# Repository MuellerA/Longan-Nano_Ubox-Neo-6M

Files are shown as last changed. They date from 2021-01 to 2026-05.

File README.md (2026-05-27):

# GPS Receiver and Logger

Using ```Longan Nano``` with an ```u-blox``` GPS module to display and record UTC time and GPS position data. The GPS receiver must implement the ubx protocol, tested with u-blox 6, 7, 10.

## Usage

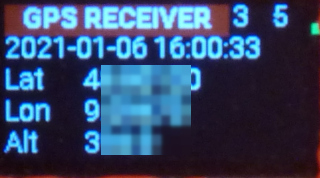
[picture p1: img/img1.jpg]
GPS Position
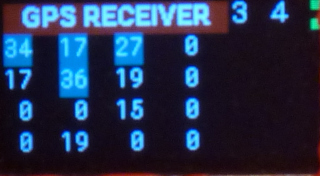
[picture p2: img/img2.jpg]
Satellite Info
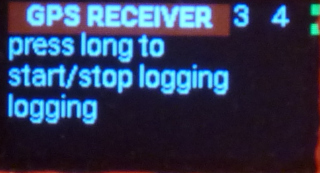
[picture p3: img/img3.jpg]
Logging
   

The GPS Receiver has three screens: *GPS Position*, *Satellite Info* and *Logging*. Use a short button press to toggle between *GPS Position* screen and *Satellite Info* screen. A long button press will select the *Logging* screen. Another long button press will start / stop logging to the SD card.

The top line of all screens show
- GPS fix (0: none; 2: 2D fix; 3: 3D fix)
- number of used satellites
- GPS module connection indicator (green blinking: connected, red: connection lost)
- Logging status indicator (red: logging off, green: logging data, yellow: waiting for data)

## Logging

The logging will start when the UTC time and GPS position are found and will then be update every five seconds. The file name will be the start UTC time with the extension csv.
Always stop logging before power off, else data will be lost and the file system might get corrupted.

The logfile format is compatible with [GPSBabel](http://www.gpsbabel.org/index.html)'s [unicsv](http://www.gpsbabel.org/htmldoc-1.7.0/fmt_unicsv.html) format. GPSBabel can convert the logfile to many different formats (try ```gpsbabel -h``` for a full list of formats). E.g. to create a kml file for Google Earth use the command:

```
gpsbabel -i unicsv -f 'yyymmdd-hhmmss.csv' -o kml -F 'yyymmdd-hhmmss.kml'
```

The [example.csv](img/example.csv) converted to Google Earth:  
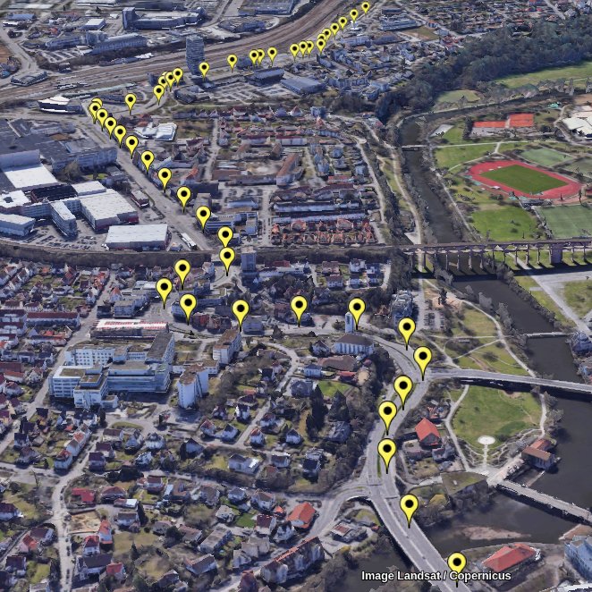
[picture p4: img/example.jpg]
example
[](img/example.jpg)

## Compilation

A ```Longan Nano``` is required, the ```Longan Nano Lite``` has not enough memory.
Use the PlatformIO environment option to select which USART the GPS module is connected to: ```-e usart0``` or ```-e usart1```.

```
pio run -e usart0 -t upload
```

## 3D Print STL Files

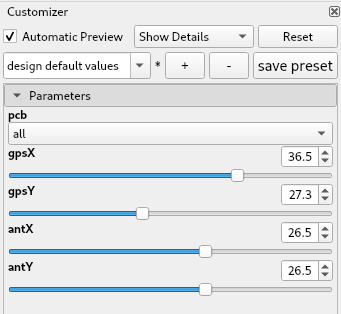
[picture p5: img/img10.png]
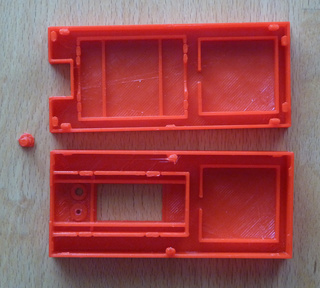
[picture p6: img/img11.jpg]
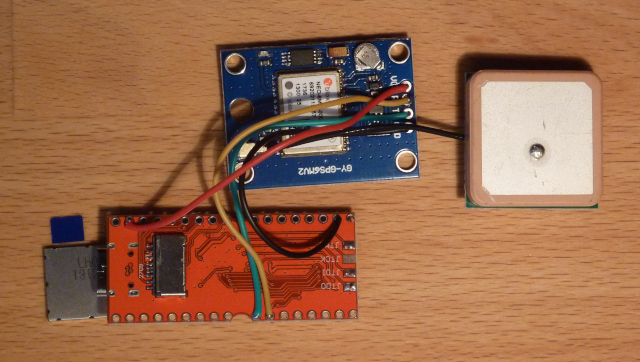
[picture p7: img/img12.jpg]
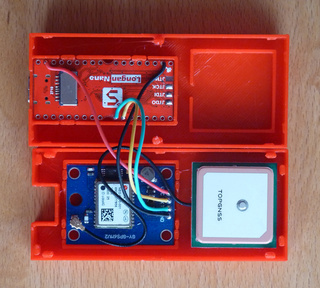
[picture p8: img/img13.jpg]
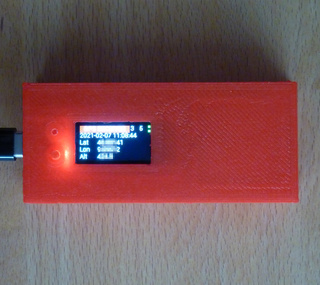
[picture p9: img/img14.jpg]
[](img/img10.png) [](img/img11.jpg) [](img/img12.jpg) [](img/img13.jpg) [](img/img14.jpg)

The [OpenSCAD](http://www.openscad.org/downloads.html) file ```hw/gps.scad``` can be used to create STL files for a 3D printed housing. The dimensions of the GPS board and antenna can be changed using the Customizer: In menu *View* uncheck *Hide Customizer*, in the Customizer dialog modify the parameters, press *F6* and then *F7* to create the STL files. When printing the button might need a brim.

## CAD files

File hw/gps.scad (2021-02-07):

////////////////////////////////////////////////////////////////////////////////
// gps.scad
////////////////////////////////////////////////////////////////////////////////

// https://github.com/MuellerA/Thingiverse.git#ac669d2e31545f4aca594795901329ed9a7b87eb
use <../../../3D Druck/Thingiverse/PCB/pcb.scad> ;

pcb = "all" ; // [top,bottom,button,all,testGps,testAnt]

// see measure.svg

gpsX = 36.5 ; // [15:0.1:45]
gpsY = 27.3 ; // [15:0.1:45]

antX = 26.5 ; // [5:0.1:40]
antY = 26.5 ; // [5:0.1:40]

/* [Hidden] */

nanoX  = 46.5 ;
nanoY  = 20.5 ;

minOX = 3 ;
minOY = 3 ;
dX    = 4 ;

minGpsOX = 9 ;

wallWidth = 0.8 ;
$fn = 40 ;

// calc total size excl outer wall

totTopX = 3*wallWidth + nanoX            + dX + antX + minOX ;
totBotX = 4*wallWidth + minGpsOX + gpsX  + dX + antX + minOX ;

totX = max(totTopX, totBotX) ;

totNanY = 2*wallWidth + 2*minOY + nanoY ;
totAntY = 2*wallWidth + 2*minOY + antY ;
totGpsY = 2*wallWidth + 2*minOY + gpsY ;

totY = max(totNanY, totAntY, totGpsY) ;

// calc offsets

offsetAntX = -antX/2 + totX - minOX - wallWidth ;
offsetGpsX = -gpsX/2 + totX - minOX - antX - dX - 3*wallWidth ;

////////////////////////////////////////////////////////////////////////////////

module base(height)
{
  translate([totX/2, 0, height/2])
    difference()
  {
    translate([0, 0, -wallWidth/2])
      cube([totX+2*wallWidth, totY+2*wallWidth, height+wallWidth], center=true) ;
    translate([0, 0, +wallWidth/2])
      cube([totX            , totY            , height+wallWidth], center=true) ;
  }
}

////////////////////////////////////////////////////////////////////////////////

module antenna()
{
  antZ = 4 ;

  difference()
  {
    translate([0, 0, antZ/2])
      cube([antX+2*wallWidth, antY+2*wallWidth, antZ], center=true) ;

    translate([0, 0, antZ/2])
      cube([antX            , antY          , 2*antZ], center=true) ;
    translate([-antX/2, 0, antZ/2])
      cube([8, 4, 2*antZ], center=true) ;
  }
}

////////////////////////////////////////////////////////////////////////////////

module gps()
{
  pcbHeight  =  1.2 ;
  wallWidth  =  0.8 ;
  railHeight =  2.0 ;
  railOffset =  8.0 ;

  clip = [ 3, 3.5 ] ;
  PcbHolder(gpsY, gpsX, pcbHeight, wallWidth, railHeight, railOffset,
            clip=clip, fingerHoleEnable=true) ;
}

////////////////////////////////////////////////////////////////////////////////

module hooks(height, top)
{
  w = wallWidth ;
  d = w/2 ;
  points =
    [
      [ [0, 0], [w, -w], [0, -2*w], [-w, -2*w], [-w, 0] ],
      [ [0, 0], [0, -2*w], [w+d, -2*w], [w+d, 0.5*w], [d, 1.5*w], [w+d, 2.5*w], [2*w+d, 2.2*w], [2*w+d, -3*w], [0, -6*w], [-w, -6*w], [-w, 0] ]
    ] ;

  module hook(points)
  {
    rotate([0, 0, 90])
      rotate([90, 0, 0])
      linear_extrude(height=3, center=true)
      polygon(points) ;
  }

  p1 = (top) ? points[0] : points[1] ;
  p2 = (top) ? points[1] : points[0] ;
  
  translate([+totX/2-5, -totY/2, height]) rotate([0, 0,   0]) hook(p1) ;
  translate([0        , -totY/2, height]) rotate([0, 0,   0]) hook(p2) ;
  translate([-totX/2+5, -totY/2, height]) rotate([0, 0,   0]) hook(p1) ;
  translate([+totX/2-5, +totY/2, height]) rotate([0, 0, 180]) hook(p1) ;
  translate([0        , +totY/2, height]) rotate([0, 0, 180]) hook(p2) ;
  translate([-totX/2+5, +totY/2, height]) rotate([0, 0, 180]) hook(p1) ;

  translate([+totX/2  , -totY/2+6  , height]) rotate([0, 0,  90]) hook(p1) ;
  translate([+totX/2  , +totY/2-6  , height]) rotate([0, 0,  90]) hook(p1) ;

  translate([-totX/2  , -totY/2+2.8, height]) rotate([0, 0, 270]) hook(p1) ;
  translate([-totX/2  , +totY/2-2.8, height]) rotate([0, 0, 270]) hook(p1) ;
}

////////////////////////////////////////////////////////////////////////////////

module top()
{
  pcbHeight  =  1.9 ;
  railHeight =  6.0 ;
  railOffset =  2.3 ;

  height = railHeight + pcbHeight + wallWidth + 1 ;
  
  dispLength = 23.9 ;
  dispWidth  = 13.5 ;
  dispOffset =  3.5 ;

  buttonD       = 3.0 ;
  buttonLoffset = nanoX / 2 - 8.9 ;
  buttonWoffset = 3.5 ;

  usbWidth  = 9.9 ;
  usbHeight = 3.9 ;
  usbOffset = 2.0 ;
  
  difference()
  {
    union()
    {
      // base
      base(height) ;

      // nano
      translate([nanoX/2, 0, 0])
      {
        // pcb frame
        rotate([0, 0, 90])
          PcbHolder(nanoX, nanoY, pcbHeight, wallWidth, railHeight, railOffset, clip = [10, 5]) ;

        translate([-dispLength/2+dispOffset-1.5*wallWidth, 0, 2/2]) cube([wallWidth, 20 , 2], center=true) ;

        // button
        bd = buttonD + 2 * 0.4 ;
        translate([-buttonLoffset, buttonWoffset, 0.51]) cylinder(d=bd+2*wallWidth, h=1, center=true) ;
        
        // reset
        translate([-buttonLoffset, -buttonWoffset, 0.51]) cylinder(d=bd+2*wallWidth, h=1, center=true) ;
      }

      // antenna
      translate([offsetAntX, 0, 0]) antenna() ;
    }

    union()
    {
      translate([nanoX/2, 0, 0])
      {
        // display
        translate([dispOffset, 0, 0]) cube([dispLength, dispWidth, 10], center=true) ;

        // button
        bd = buttonD + 2 * 0.4 ;
        translate([-buttonLoffset, buttonWoffset, 0]) cylinder(d=bd, h=10, center=true) ;

        // reset
        translate([-buttonLoffset, -buttonWoffset, 0]) cylinder(d=2, h=10, center=true) ;

        // usb
        translate([-nanoX/2, 0, usbHeight/2+usbOffset])
          cube([5, usbWidth, usbHeight], center=true) ;

        // sdcard
        translate([-nanoX/2, 0, railHeight + pcbHeight + 2])
          cube([5, 12, 4], center=true) ;
      }
    }
  }

  translate([totX/2, 0, 0])
    hooks(height, true) ;
}

////////////////////////////////////////////////////////////////////////////////

module bottom()
{
  sdcardX =  7 ;
  sdcardY = 12 ;
  
  height = 7 ;

  difference()
  {
    union()
    {
      // base
      base(height) ;

      // sdcard
      translate([(sdcardX)/2, 0, height/2])
        cube([sdcardX+2*wallWidth, sdcardY+2*wallWidth, height], center=true) ;

      // gps
      {
        translate([offsetGpsX, 0, 0])
          gps() ;
      }
      
      // antenna
      translate([offsetAntX, 0, 0]) antenna() ;
    }

    union()
    {
      // sdcard
      translate([(sdcardX)/2-wallWidth, 0, height/2])
        cube([sdcardX+2*wallWidth, sdcardY, height*2], center=true) ;
      translate([sdcardX+wallWidth/2, 0, height])
        cube([2*wallWidth, sdcardY, 2], center=true) ;
    }
  }   
  
  translate([totX/2, 0, 0])
    hooks(height, false) ;
}

////////////////////////////////////////////////////////////////////////////////

module button()
{
  cylinder(h=1, d=4.4) ;
  cylinder(h=6, d=2.5) ;
}

////////////////////////////////////////////////////////////////////////////////

if (pcb == "top")
  top() ;
else if (pcb == "bottom")
  bottom() ;
else if (pcb == "button")
  button() ;
else if (pcb == "all")
{
  translate([0, -totY/2 - 5, 0]) bottom() ;
  translate([0, +totY/2 + 5, 0]) top() ;
  translate([-10, 0, -wallWidth]) button() ;
}
else if (pcb == "testGps")
{
  translate([0, 0, -wallWidth/2])
    cube([gpsX+2*wallWidth, gpsY+2*wallWidth, wallWidth], center=true) ;
  gps() ;
}
else if (pcb == "testAnt")
{
  translate([0, 0, -wallWidth/2])
    cube([antX+2*wallWidth, antY+2*wallWidth, wallWidth], center=true) ;
  antenna() ;
}

////////////////////////////////////////////////////////////////////////////////
// EOF
////////////////////////////////////////////////////////////////////////////////

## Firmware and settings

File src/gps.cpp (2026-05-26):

//////////////////////////////////////////////////////////////////////////////
// gps.cpp
////////////////////////////////////////////////////////////////////////////////

#include "disp.h"
#include "ubx.h"
#include "file.h"
#include "Longan/fatfs.h"
#include "Longan/lcd.h"
#include "GD32VF103/gpio.h"

using ::RV::GD32VF103::Gpio ;
using ::RV::Longan::FatFs ;
using ::RV::Longan::Lcd ;

Gpio &button(Gpio::gpioA8()) ;
FatFs &fatfs{FatFs::fatfs()} ;
extern Lcd &lcd ;

volatile bool ubxAscFound{false} ;

////////////////////////////////////////////////////////////////////////////////

int _put_char(int ch) // used by printf
{
  lcd.put((char)ch) ;
  return ch ;
}

////////////////////////////////////////////////////////////////////////////////

uint8_t buttonPressed()
{
  struct State
  {
    State() : _value{0x00}, _tick{TickTimer::now()} {}
    uint8_t  _value ;
    uint64_t _tick ;
  } ;
  static State last ;
  static State current ;

  uint64_t now = TickTimer::now() ;
  if ((now - current._tick) < TickTimer::usToTick(2500))
    return 0 ;

  current._tick = now ;
  current._value = (current._value << 1) | button.get() ;
  if ((current._value == last._value) ||
      ((current._value != 0x00) && (current._value != 0xff)))
    return 0 ;

  uint32_t ms = TickTimer::tickToMs(current._tick - last._tick) ;
  last = current ;
  if (current._value)
    return 0 ;
  return (ms < 600) ? 1 : 2 ;
}

void getTimeUtc(const UbxNav &nav, FatFs::Time &time)
{
  if (!nav.timeUtcValid())
    return ;

  const UbxNavTimeUtc &timeUtc = nav.timeUtc() ;
  if (timeUtc.valid & 0b100)
  {
    time.year   = timeUtc.year - 2000 ;
    time.month  = timeUtc.month ;
    time.day    = timeUtc.day ;
    time.hour   = timeUtc.hour ;
    time.minute = timeUtc.min ;
    time.second = timeUtc.sec ;
  }
}

////////////////////////////////////////////////////////////////////////////////

int main()
{
  button.setup(Gpio::Mode::IN_FL) ;

  dispSetup() ;
  {
    lcd.color(0xffffffUL, 0xa00000UL) ;
    lcd.clear() ;
    lcd.put("https://git.io/JLHU1", 80, 48) ;
    lcd.font(&::RV::Longan::Roboto_Bold7pt7b) ;
    lcd.put("GPS RECEIVER 2.0", 80, 24) ;
    
    LcdArea laUbx(Lcd::lcd(), 0, 160, 64, 16) ;
    laUbx.clear() ;
    ubxSetup(laUbx) ;

    TickTimer t(1250) ;
    bool bp = false ;
    while (!t())
      bp |= buttonPressed() ;
    if (bp)
      while (!buttonPressed()) ;
    
    lcd.clear(0x000000UL) ;
    lcd.put("   GPS RECEIVER   ") ;
  }
  
  LcdArea laData(Lcd::lcd(), 0, 150, 16, 64) ;
  
  UbxRx ubxRx ;

  DispGpsFix    dispGpsFix ;
  DispSats      dispSats   ;
  DispTow       dispTow    ;
  DispSvInfo    dispSvInfo ;
  DispTime      dispTime   ;
  DispPos       dispPos    ;
  DispFile      dispFile   ;
  DispAscFound  dispAscFound(1100) ;
  DispFileState dispFileState ;
  
  UbxNav ubxNav ;

  fatfs.setup([&ubxNav](FatFs::Time &time){ getTimeUtc(ubxNav, time) ; }) ;
  File logging(fatfs, ubxNav) ;

  enum class Page { main, sat, file } ;
  Page page{Page::main} ;
  
  bool force{true} ;
  uint8_t sched{0} ;

  dispPos.label() ;
  
  while (true)
  {
    while (ubxRx.poll())
    {
      if (ubxRx.valid())
      {
        if (ubxRx.clsId() == 0x01) // Nav
        {
          switch (ubxRx.msgId())
          {
          case 0x02: ubxNav.posllh (ubxRx.data()) ; break ;
          case 0x03: ubxNav.status (ubxRx.data()) ; break ;
          case 0x21: ubxNav.timeUtc(ubxRx.data()) ; break ;
          case 0x30: ubxNav.svinfo (ubxRx.data()) ; break ;
          case 0x35: ubxNav.sat    (ubxRx.data()) ; break ;
          }
        }
      }
      ubxRx.reset() ;
    }

    if (ubxAscFound)
    {
      ubxAscFound = false ;
      dispAscFound.set() ;
    }

    switch (sched)
    {
    case 0: // handle button
      switch (buttonPressed())
      {
      case 1: // short
        {
          laData.clear() ;
          force = true ;
          switch (page)
          {
          case Page::main:
            page = Page::sat ;
            break ;
          case Page::sat:
          case Page::file:
            page = Page::main ;
            dispPos.label() ;
            break ;
          }
        }
        break ;
      case 2: // long
        {
          switch (page)
          {
          case Page::main:
          case Page::sat:
            laData.clear() ;
            force = true ;
            page = Page::file ;
            break ;
          case Page::file:
            if (logging.state() == File::State::closed)
              logging.open() ;
            else
              logging.close() ;
            break ;
          }
        }
        break ;
      }
      break ;
    case 1: // update display
      {
        dispGpsFix  .display(ubxNav, false) ;
        dispSats    .display(ubxNav, false) ;
        dispTow     .display(ubxNav, false) ;
        dispFile    .display(logging, false) ;

        switch (page)
        {
        case Page::main:
          dispTime    .display(ubxNav, force) ;
          dispPos     .display(ubxNav, force) ;
          dispAscFound.display(force) ;
          break ;
        case Page::sat:
          dispSvInfo  .display(ubxNav, force) ;
          break ;
        case Page::file:
          if (force)
          {
            laData.txtPos(0) ; laData.put("press long to") ;
            laData.txtPos(1) ; laData.put("start/stop logging") ;
          }
          dispFileState.display(logging, force) ;
          break ;
        }

        force = false ;
      }
      break ;
    case 2: // update sd card
      {
        logging.loop() ;
      }
      break ;
    }
    sched = (sched + 1) % 3 ;
  }
}

////////////////////////////////////////////////////////////////////////////////
// EOF
////////////////////////////////////////////////////////////////////////////////

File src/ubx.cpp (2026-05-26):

////////////////////////////////////////////////////////////////////////////////
// ubx.cpp
////////////////////////////////////////////////////////////////////////////////

#include "disp.h"
#include "ubx.h"

#include "GD32VF103/time.h"
#include "GD32VF103/usart.h"
#include "Longan/toStr.h"

using ::RV::GD32VF103::TickTimer ;
using ::RV::GD32VF103::Usart ;

////////////////////////////////////////////////////////////////////////////////

#ifdef USART_GPS
Usart& usart(Usart::USART_GPS()) ;
#else
#error "undefined USART (-D USART_GPS=usartN)"
#endif

////////////////////////////////////////////////////////////////////////////////

UbxId::UbxId(uint8_t clsId, uint8_t msgId) :
  _clsId{clsId}, _msgId{msgId}
{
}

UbxId::UbxId() :
  _clsId{0}, _msgId{0}
{
}

bool UbxId::operator==(const UbxId &that) const
{
  return
    (_clsId == that._clsId) &&
    (_msgId == that._msgId) ;
}

uint8_t UbxId::clsId() const { return _clsId ; }
uint8_t UbxId::msgId() const { return _msgId ; }
uint8_t& UbxId::clsId() { return _clsId ; }
uint8_t& UbxId::msgId() { return _msgId ; }

UbxId UbxId::NavPosllh (0x01, 0x02) ;
UbxId UbxId::NavStatus (0x01, 0x03) ;
UbxId UbxId::NavTimeUtc(0x01, 0x21) ;
UbxId UbxId::NavSvinfo (0x01, 0x30) ;
UbxId UbxId::NavSat    (0x01, 0x35) ;

UbxId UbxId::AckAck    (0x05, 0x01) ;
UbxId UbxId::AckNak    (0x05, 0x00) ;

UbxId UbxId::CfgPrt    (0x06, 0x00) ;
UbxId UbxId::CfgMsg    (0x06, 0x01) ;

////////////////////////////////////////////////////////////////////////////////

UbxTx UbxCfgPrtUart::ubxTx()
{
  return UbxTx(UbxId::CfgPrt, std::vector<uint8_t>((uint8_t*)this, (uint8_t*)(this+1))) ;
}

////////////////////////////////////////////////////////////////////////////////

bool ack(const UbxId &ubxId, const std::vector<uint8_t> data)
{
  if (data.size() < sizeof(UbxAck))
    return false ;

  const UbxAck *ubx = (const UbxAck*) data.data() ;
  return (ubxId.clsId() == ubx->clsId) && (ubxId.msgId() == ubx->msgId) ;
}

////////////////////////////////////////////////////////////////////////////////

UbxNav::UbxNav()
{
  _lastTow = ~0UL ;
  _posllh.iTOW = ~0UL ;
  _status.iTOW = ~0UL ;
  _svinfo.iTOW = ~0UL ;
  _sat.iTOW    = ~0UL ;
  _timeUtc.iTOW = ~0UL ;
}

bool UbxNav::posllhValid()  const { return valid(_posllh .iTOW, 10000) ; }
bool UbxNav::statusValid()  const { return valid(_status .iTOW, 10000) ; }
bool UbxNav::svinfoValid()  const { return valid(_svinfo .iTOW, 10000) ; }
bool UbxNav::satValid()     const { return valid(_sat    .iTOW, 10000) ; }
bool UbxNav::timeUtcValid() const { return valid(_timeUtc.iTOW,  5000) ; }

bool UbxNav::valid() const
{
  uint32_t tow = _lastTow ;
  return valid(tow,  2000) ;
}

uint32_t UbxNav::lastTow() const { return _lastTow ; }

const UbxNavPosllh& UbxNav::posllh() const { return _posllh ; }
const UbxNavStatus& UbxNav::status() const { return _status ; }
const UbxNavSvinfo& UbxNav::svinfo() const { return _svinfo ; }
const std::vector<UbxNavSvinfoRep>& UbxNav::svinfoRep() const { return _svinfoRep ; }
const UbxNavSat& UbxNav::sat() const { return _sat ; }
const std::vector<UbxNavSatRep>& UbxNav::satRep() const { return _satRep ; }
const UbxNavTimeUtc& UbxNav::timeUtc() const { return _timeUtc ; }

std::string UbxNav::timeUtcStr(bool compressed) const
{
  if (compressed)
  {
    //  0123456789012345678
    // "xxxxxxxx xxxxxx"
    char text[15] ;
    RV::toStr(_timeUtc.year , text+ 0, 4, '0') ;
    RV::toStr(_timeUtc.month, text+ 4, 2, '0') ;
    RV::toStr(_timeUtc.day  , text+ 6, 2, '0') ; text[8] = ' ' ;
    RV::toStr(_timeUtc.hour , text+ 9, 2, '0') ;
    RV::toStr(_timeUtc.min  , text+11, 2, '0') ;
    RV::toStr(_timeUtc.sec  , text+13, 2, '0') ;
    return std::string(text, 15) ;
  }
  else
  {
    //  0123456789012345678
    // "xxxx-xx-xx xx:xx:xx"
    char text[19] ;
    RV::toStr(_timeUtc.year , text+ 0, 4, '0') ; text[ 4] = '-' ;
    RV::toStr(_timeUtc.month, text+ 5, 2, '0') ; text[ 7] = '-' ;
    RV::toStr(_timeUtc.day  , text+ 8, 2, '0') ; text[10] = ' ' ;
    RV::toStr(_timeUtc.hour , text+11, 2, '0') ; text[13] = ':' ;
    RV::toStr(_timeUtc.min  , text+14, 2, '0') ; text[16] = ':' ;
    RV::toStr(_timeUtc.sec  , text+17, 2, '0') ;
    return std::string(text, 19) ;
  }
}

std::string UbxNav::latStr() const
{
  int32_t lat = _posllh.lat / 100 ;
  int32_t g = lat / 100000 ;
  int32_t t = lat - g * 100000 ;
  if (t < 0) t = -t ;
  char text[32] ;
  char *start = RV::toStr(g, text, 16) ;
  text[16] = '.' ;
  RV::toStr(t, text+17, 5, '0') ;
  return std::string(start, 16 - (start-text) + 6) ;
}

std::string UbxNav::lonStr() const
{
  int32_t lon = _posllh.lon / 100 ;
  int32_t g = lon / 100000 ;
  int32_t t = lon - g * 100000 ;
  if (t < 0) t = -t ;
  char text[32] ;
  char *start = RV::toStr(g, text, 16) ;
  text[16] = '.' ;
  RV::toStr(t, text+17, 5, '0') ;
  return std::string(start, 16 - (start-text) + 6) ;
}

std::string UbxNav::altStr() const
{
  int32_t alt = _posllh.alt / 100 ;
  int32_t g = alt / 10 ;
  int32_t t = alt - g * 10 ;
  if (t < 0) t = -t ;
  char text[32] ;
  char *start = RV::toStr(g, text, 16) ;
  text[16] = '.' ;
  RV::toStr(t, text+17, 1, '0') ;
  return std::string(start, 16 - (start-text) + 2) ;
}

uint8_t UbxNav::sats() const
{
  uint32_t sat{0} ;
  if (svinfoValid())
  {
    for (const UbxNavSvinfoRep &svInfoRep : _svinfoRep)
      if (svInfoRep.flags & 1)
        sat += 1 ;
  }
  else if (satValid())
  {
    for (const UbxNavSatRep &satRep : _satRep)
      if (satRep.flags & 0x08)
        sat += 1 ;
  }
  return sat ;
}

bool UbxNav::posllh(const std::vector<uint8_t> &data)
{
  if (data.size() < sizeof(UbxNavPosllh))
    return false ;

  _posllh = *(const UbxNavPosllh*) data.data() ;
  tow(_posllh.iTOW) ;
  return true ;
}

bool UbxNav::svinfo(const std::vector<uint8_t> &data)
{
  if (data.size() < sizeof(UbxNavSvinfo))
    return false ;
  const UbxNavSvinfo *svinfo = (const UbxNavSvinfo*) data.data() ;
  if (data.size() < (sizeof(UbxNavSvinfo) + svinfo->numCh * sizeof(UbxNavSvinfoRep)))
    return false ;
  
  _svinfo = *(const UbxNavSvinfo*) data.data() ;
  tow(_svinfo.iTOW) ;
  _svinfoRep.clear() ;
  _svinfoRep.reserve(_svinfo.numCh) ;
  for (uint8_t iCh = 0 ; iCh < _svinfo.numCh ; ++iCh)
    _svinfoRep.emplace_back(*(const UbxNavSvinfoRep*)(data.data() + sizeof(UbxNavSvinfo) + iCh * sizeof(UbxNavSvinfoRep))) ;
  return true ;
}

bool UbxNav::sat(const std::vector<uint8_t> &data)
{
  if (data.size() < sizeof(UbxNavSat))
    return false ;
  const UbxNavSat *sat = (const UbxNavSat*) data.data() ;
  if (data.size() < (sizeof(UbxNavSat) + sat->numSvs * sizeof(UbxNavSatRep)))
    return false ;
  
  _sat = *(const UbxNavSat*) data.data() ;
  tow(_sat.iTOW) ;
  _satRep.clear() ;
  _satRep.reserve(_sat.numSvs) ;
  for (uint8_t iCh = 0 ; iCh < _sat.numSvs ; ++iCh)
    _satRep.emplace_back(*(const UbxNavSatRep*)(data.data() + sizeof(UbxNavSat) + iCh * sizeof(UbxNavSatRep))) ;
  return true ;
}
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

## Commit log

2020-08-23 probe baud rate, use 115200 baud
2020-08-29 display satellite signal strength and in use on second page (change page with BOOT0 button)
2020-08-29 fix connection lost behaviour, update jpg
    [gps.cpp]
2020-12-06 add openscad 3D file
    [gps.scad]
2020-12-27 change button press, log number of sats
    [bottom.stl, button.stl, gps.scad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]
2021-01-08 hw: reset hole; sw: ui txt
    [gps.scad, top.stl]
2021-02-07 3D customizable, Readme
    [bottom.stl, button.stl, gps.scad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]
